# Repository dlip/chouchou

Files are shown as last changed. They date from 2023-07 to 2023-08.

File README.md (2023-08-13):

# Chouchou Keyboard/Fight Pad

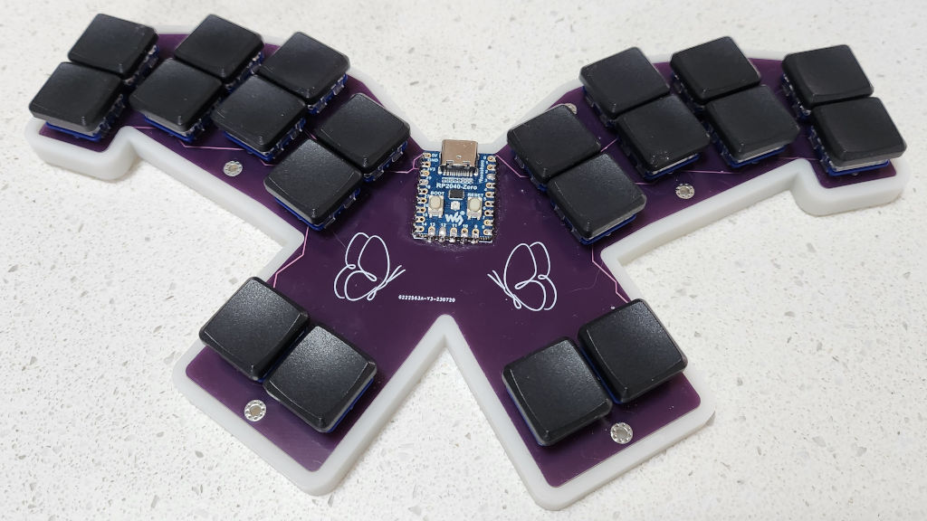
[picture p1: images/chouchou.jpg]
Chouchou


Chouchou (Japanese for butterfly) is a minimalist unibody keyboard designed to be used with the [Taipo](https://inkeys.wiki/en/keymaps/taipo) layout, but it also can be used as a pretty nice fighting gamepad.

It uses a cheap RP2040-Zero MCU and requires no diodes since the 20 edge pinouts it provides is the exact number of keys Taipo requires. It was created with [Ergogen](https://github.com/ergogen/ergogen) and [KiCad](https://www.kicad.org). I designed it for my largish hands so if you have smaller hands its probably not going to be comfortable. I might make a more compact version in the future if people request it.

## Fight Pad / Pin Layout

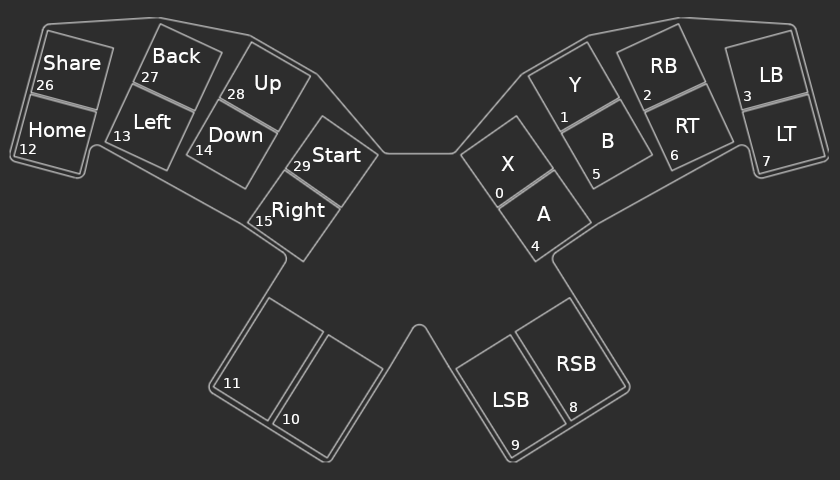
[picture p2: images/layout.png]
Layout


## Build Your Own

### Board

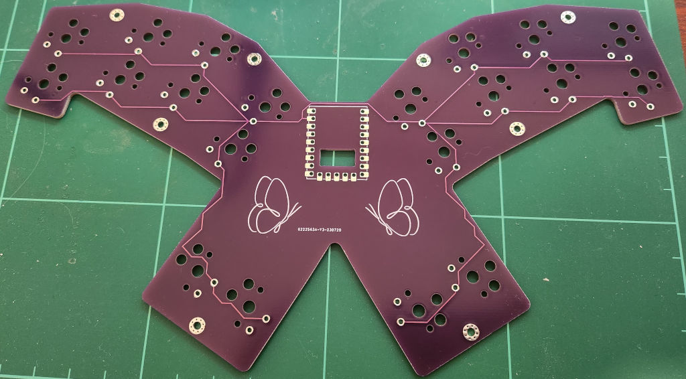
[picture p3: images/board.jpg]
Board


#### Parts

- Send the [Gerber](kicad/gerber_to_order) file to the PCB manufacturer of your choice
- 1 x RP2040-Zero
- 20 x low profile choc switches and keycaps. Since you're going to be doing a lot of combos, I recommend lighter switches. I use 25g light blue, but 35g pro red is not bad either. You can use 1.5U keycaps for the thumbs, the socket has been rotated 90 degrees to accomodate.
- (optional) 20 x kailh hotswap sockets
- (optional) RP2040-Zero headers

#### Firmware

- [QMK](https://github.com/dlip/qmk_firmware/tree/chouchou/keyboards/chouchou)
  - Taipo Keyboard
  - PC Gamepad
  - Qwerty/WASD Layout
- [KMK](firmware/kmk)
  - Taipo Keyboard
  - Python based with hot reloading so good if you tinker a lot with your layout
- [GP2040-CE](firmware/gp2040-ce)
  - PC or console gamepad
  - Note: PS5 requires an adapter like the [Wingman FGC](https://shop.brookaccessory.com/en/products/wingman-fgc)

#### Instructions

- Solder the RP2040-Zero to the board either directly or using the headers you purchased
- Build and flash the firmware
- You can test the keyboard at this point by connecting the hotswap pads with some metal tweezers before continuing
- Solder the kalih hotswap sockets if purchased or solder the switches directly the board otherwise
- Insert the switches into the hotswap sockets if necessary
- Add your keycaps 

### Case

Issue: The case gets blocked by one of the screw mounts when using hotswap sockets, its easy enough to cut the side a bit with a knife though. 

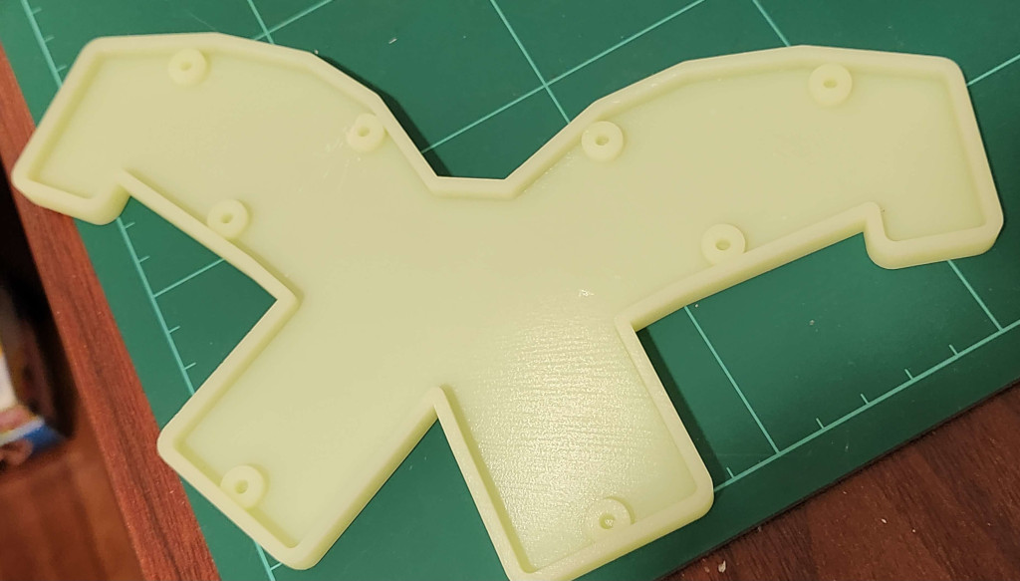
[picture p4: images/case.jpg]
Case


#### Parts

The screws/nuts are optional, its a pretty tight fit so you might not need them.

- 3D print the [case.stl](case/case.stl) file
- (optional)  8 x Knurled Insert Nuts (M2 x 3mm Length x 3.2mm OD) [example](https://www.amazon.com/dp/B07LBQFNQD)
- (optional) 8 x M2 3mm flat screws [example](https://www.amazon.com/gp/product/B01FTI8TM8/) 

#### Instructions

- Use a soldering iron to melt the insert nuts into the holes in the case
- Screw the board to the case

### Attribution

Butterfly image by [Freepik](https://www.freepik.com/free-vector/hand-drawn-butterfly-outline-pack_15636314.htm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)

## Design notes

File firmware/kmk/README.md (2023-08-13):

# Chouchou KMK Firmware

## Installation

- Install KMK by following the first three points of the [quickstart guide](http://kmkfw.io/docs/Getting_Started/#tldr-quick-start-guide)
- Copy the `*.py` files from this directory to the mounted drive

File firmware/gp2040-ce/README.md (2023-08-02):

# Chouchou GP2040-CE Firmware

## Instructions

- Download the firmware for the [Waveshare RP2040-Zero](https://gp2040-ce.info/#/download)
- Hold the RP2040 boot button while connecting the USB
- Copy the firmware to the drive that appears
- Disconnect the USB and hold key 1 from layout below, while connecting the USB
- Open your browser at http://192.168.7.1
- Select "Configuration", "Data Backup and Restoration"
- Under "Restore From File" select "Load"
- Select the `chouchou.gp2040` file in this folder
- Select "Reboot" -> "Controller"
- To get back to the configuration webpage in the future, hold key 29 (start) while connecting the USB

## Layout

The default layout is below, but you can change keys by reassign them using the pin numbers below under the "Configuration" -> "Pin Mapping" menu. For example, to use a Hitbox style up arrow, set Up to pin 10. 

Layout

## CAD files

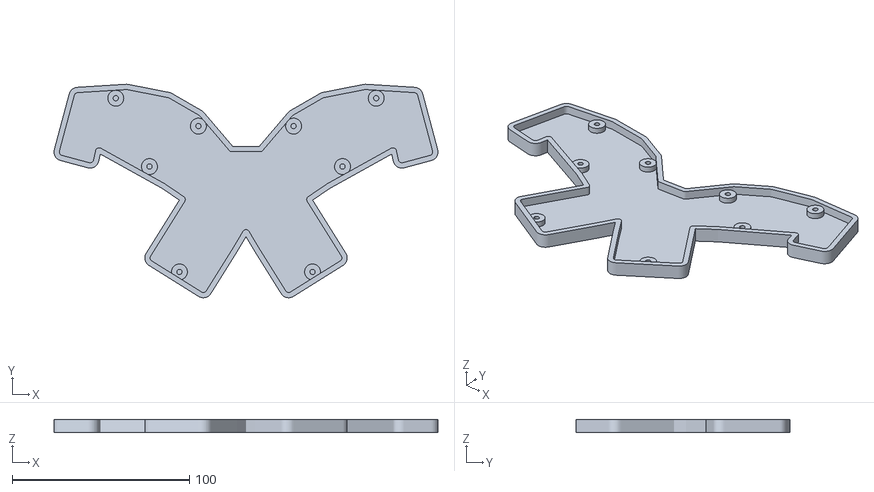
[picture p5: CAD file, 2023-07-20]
case/case.stl
216.5 x 120.4 x 7.60

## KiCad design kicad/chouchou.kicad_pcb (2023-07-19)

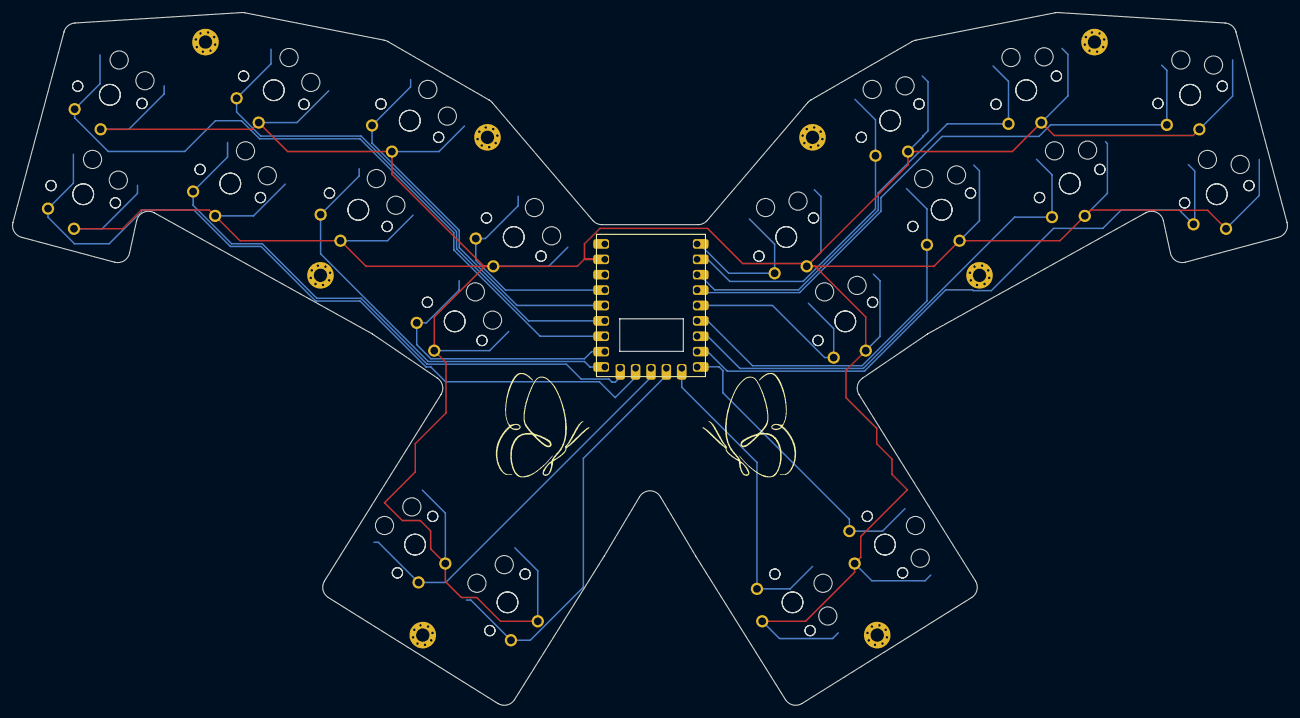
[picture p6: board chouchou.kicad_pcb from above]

Board: 2 copper layers, 210.5 x 114.4 mm, 49 parts (0 on the bottom side), 21 nets.

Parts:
RP2040Zero1: RP2040-Zero
S1, S2, S3, S4, S5, S6, S7, S8, S9, S10, S11, S12, S13, S14, S15, S16, S17, S18, S19, S20, S21, S22, S23, S24, S25, S26, S27, S28, S29, S30, S31, S32, S33, S34, S35, S36, S37, S38, S39, S40: PG1350
_1, _2, _3, _4, _5, _6, _7, _8: MountingHole_2.2mm_M2_Pad_Via

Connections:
GND: RP2040Zero1.20, S1.2, S2.2, S3.2, S4.2, S5.2, S6.2, S7.2, S8.2, S9.2, S10.2, S11.2, S12.2, S13.2, S14.2, S15.2, S16.2, S17.2, S18.2, S19.2, S20.2, S21.2, S22.2, S23.2, S24.2, S25.2, S26.2, S27.2, S28.2, S29.2, S30.2, S31.2, S32.2, S33.2, S34.2, S35.2, S36.2, S37.2, S38.2, S39.2, S40.2
GP0: RP2040Zero1.1, S18.1, S38.1
GP1: RP2040Zero1.2, S16.1, S36.1
GP2: RP2040Zero1.3, S14.1, S34.1
GP3: RP2040Zero1.4, S12.1, S32.1
GP4: RP2040Zero1.5, S17.1, S37.1
GP5: RP2040Zero1.6, S15.1, S35.1
GP6: RP2040Zero1.7, S13.1, S33.1
GP7: RP2040Zero1.8, S11.1, S31.1
GP8: RP2040Zero1.9, S19.1, S39.1
GP9: RP2040Zero1.10, S20.1, S40.1
GP10: RP2040Zero1.11, S10.1, S30.1
GP11: RP2040Zero1.12, S9.1, S29.1
GP12: RP2040Zero1.13, S1.1, S21.1
GP13: RP2040Zero1.14, S3.1, S23.1
GP14: RP2040Zero1.15, S5.1, S25.1
GP15: RP2040Zero1.16, S7.1, S27.1
GP26: RP2040Zero1.17, S2.1, S22.1
GP27: RP2040Zero1.18, S4.1, S24.1
GP28: RP2040Zero1.22, S6.1, S26.1
GP29: RP2040Zero1.23, S8.1, S28.1

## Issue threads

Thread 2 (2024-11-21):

rp2040 footprint cut out

michelepagot, 2024-11-21:
Hi @dlip, amazing work.

I'd like to use waveshare rp2040 zero in a board of mine and I'm searching for an Ergogen footprint for it.

I noticed yours is using a cut out to support flush soldering, I'm just not sure its ok for the waveshare module I have.

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

Here another board is using similar footprint: https://github.com/axhixh/mini-kbd/ : from the picture there seems that the MCU module is also mounted on pin headers and not soldered flush on the main board, so there looks like the hole is about heat dissipation.

dlip, 2024-11-21:
@michelepagot I thought it was a hole for the cpu originally at first also, but it's actually for the reset buttons in case you want to design a reversible board. If you want to do it without headers, it will work if you add blobs of soldier to the pcb first, then place the mcu on top and join that up to the side of the castellated holes.

Closed 2024-11-28.

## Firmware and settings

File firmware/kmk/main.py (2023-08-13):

from kmk.extensions.media_keys import MediaKeys
from kmk.keys import KC
from kmk.modules.oneshot import OneShot

from kb import ChouChou
from taipo import Taipo

keyboard = ChouChou()

# keyboard.debug_enabled = True
keyboard.extensions.append(MediaKeys())
keyboard.modules.append(Taipo())
keyboard.modules.append(OneShot())

keyboard.keymap = [
    [  KC.TP_TLP,    KC.TP_TLR,    KC.TP_TLM,       KC.TP_TLI,          KC.TP_TRI,     KC.TP_TRM,     KC.TP_TRR,     KC.TP_TRP,
       KC.TP_BLP,    KC.TP_BLR,    KC.TP_BLM,       KC.TP_BLI,          KC.TP_BRI,     KC.TP_BRM,     KC.TP_BRR,     KC.TP_BRP,
                                   KC.TP_LIT,       KC.TP_LOT,          KC.TP_ROT,     KC.TP_RIT,
]]

if __name__ == '__main__':
    keyboard.go()

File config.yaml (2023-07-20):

units:
  # Proxy Spacing Variables
  kx: cx
  ky: cy
  # Padding Variables
  px: kx + 2
  py: ky + 2
  # Double Padding Variables
  dpx: kx + 8
  dpy: ky + 8
  # M2 Screw Inserts
  screwRadius: 1.5
  standoffThickness: 3
  standoffDepth: 3
  # Case
  pcbThickness: 1.6
  baseThickness: 3
  wallThickness: 3
points:
  zones:
    matrix:
      anchor:
        shift: [100, -100]
      rotate: -30
      key:
        padding: 1ky
      columns:
        pinky:
          key:
            splay: 15
          rows:
            top.mcu_pin: GP26
            bottom.mcu_pin: GP12
            top.mirror.mcu_pin: GP3
            bottom.mirror.mcu_pin: GP7
        ring:
          key:
            stagger: 8
            spread: 23
            splay: -10
          rows:
            top.mcu_pin: GP27
            bottom.mcu_pin: GP13
            top.mirror.mcu_pin: GP2
            bottom.mirror.mcu_pin: GP6
        middle:
          key:
            stagger: 5
            spread: 21
            splay: -5
          rows:
            top.mcu_pin: GP28
            bottom.mcu_pin: GP14
            top.mirror.mcu_pin: GP1
            bottom.mirror.mcu_pin: GP5
        index:
          key:
            stagger: -8
            spread: 23
            splay: -5
          rows:
            top.mcu_pin: GP29
            bottom.mcu_pin: GP15
            top.mirror.mcu_pin: GP0
            bottom.mirror.mcu_pin: GP4
      rows:
        bottom:
        top:
    thumbs:
      key:
        padding: 1ky
        spread: 1kx
      anchor:
        ref: matrix_index_bottom
        shift: [14, 0]
      columns:
        inner:
          key:
            width: 1.5kx
            splay: 3
            rotate: 90
            mcu_pin: GP11
            mirror.mcu_pin: GP8
        outer:
          key:
            width: 1.5kx
            rotate: 90
            mcu_pin: GP10
            mirror.mcu_pin: GP9
      rows:
        cluster:
          shift: [0, -2ky]
  mirror: &mirror
    ref: matrix_index_top
    distance: 2.5kx
outlines:
  raw:
    - what: rectangle
      where: true
      size: [px, py]
  keys:
    - what: rectangle
      where: true
      size: [kx-0.5,ky-0.5]
    - what: rectangle
      where: thumbs_inner_cluster
      size: [1.5kx,ky-0.5]
    - what: rectangle
      where: thumbs_outer_cluster
      size: [1.5kx,ky-0.5]
    - what: rectangle
      where: mirror_thumbs_inner_cluster
      size: [1.5kx,ky-0.5]
    - what: rectangle
      where: mirror_thumbs_outer_cluster
      size: [1.5kx,ky-0.5]
  board:
    - what: polygon
      operation: stack
      fillet: 2
      points:
        - ref: matrix_pinky_top
          shift: [-0.5px,0.5py]
        - ref: matrix_ring_top
          shift: [-0.5px,0.5py]
        - ref: matrix_middle_top
          shift: [-0.5px,0.5py]
        - ref: matrix_middle_top
          shift: [0.5px,0.5py]
        - ref: matrix_index_top
          shift: [0.5px,0.5py]
        - ref: mirror_matrix_index_top
          shift: [0.5px,0.5py]
        - ref: mirror_matrix_middle_top
          shift: [0.5px,0.5py]
        - ref: mirror_matrix_middle_top
          shift: [-0.5px,0.5py]
        - ref: mirror_matrix_ring_top
          shift: [-0.5px,0.5py]
        - ref: mirror_matrix_pinky_top
          shift: [-0.5px,0.5py]
        - ref: mirror_matrix_pinky_bottom
          shift: [-0.5px,-0.5py]
        - ref: mirror_matrix_pinky_bottom
          shift: [0.5px,-0.5py]
        - ref: mirror_matrix_ring_bottom
          shift: [-0.6px,-0.5py]
        - ref: mirror_matrix_index_bottom
          shift: [-0.5px,-0.5py]
        - ref: mirror_thumbs_inner_cluster
          shift: [1.26px,0.5py]
        - ref: mirror_thumbs_inner_cluster
          shift: [0.75px,0.5py]
        - ref: mirror_thumbs_inner_cluster
          shift: [-0.75px,0.5py]
        - ref: mirror_thumbs_inner_cluster
          shift: [-0.75px,-0.5py]
        - ref: mirror_thumbs_outer_cluster
          shift: [-0.75px,-0.5py]
        - ref: mirror_thumbs_outer_cluster
          shift: [0.75px,-0.5py]
        - ref:
            aggregate.parts: [matrix_index_top, mirror_matrix_index_top]
            shift: [0,-40]
        - ref: thumbs_outer_cluster
          shift: [0.75px,-0.5py]
        - ref: thumbs_outer_cluster
          shift: [-0.75px,-0.5py]
        - ref: thumbs_inner_cluster
          shift: [-0.75px,-0.5py]
        - ref: thumbs_inner_cluster
          shift: [-0.75px,0.5py]
        - ref: thumbs_inner_cluster
          shift: [1.26px,0.5py]
        - ref: matrix_index_bottom
          shift: [-0.5px,-0.5py]
        - ref: matrix_ring_bottom
          shift: [-0.6px,-0.5py]
        - ref: matrix_pinky_bottom
          shift: [0.5px,-0.5py]
        - ref: matrix_pinky_bottom
          shift: [-0.5px,-0.5py]
  xlBoard:
    - what: outline
      name: board
      expand: wallThickness
  combo:
    - name: board
    - operation: subtract
      name: keys
  case:
    - name: xlBoard
    - operation: subtract
      name: board
    - operation: add
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

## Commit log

2023-07-17 Add kicad project
    [chouchou.kicad_pcb, chouchou.kicad_sch]
2023-07-17 add wiring
    [chouchou.kicad_pcb]
2023-07-18 Update design
    [chouchou.kicad_pcb]
2023-07-18 Add case
2023-07-18 Add images
    [case.stl, chouchou.kicad_pcb]
2023-07-19 move screws
2023-07-19 update case holes
2023-07-19 Add ordered files
    [case.stl, chouchou.kicad_pcb]
2023-07-19 use gerber to order plugin
2023-07-20 Increase case thickness
    [case.stl]
2023-07-29 Add case image
2023-07-29 Add board image
2023-07-29 Add switch comment
